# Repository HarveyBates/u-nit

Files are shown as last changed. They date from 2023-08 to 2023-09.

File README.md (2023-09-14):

<p align="center">
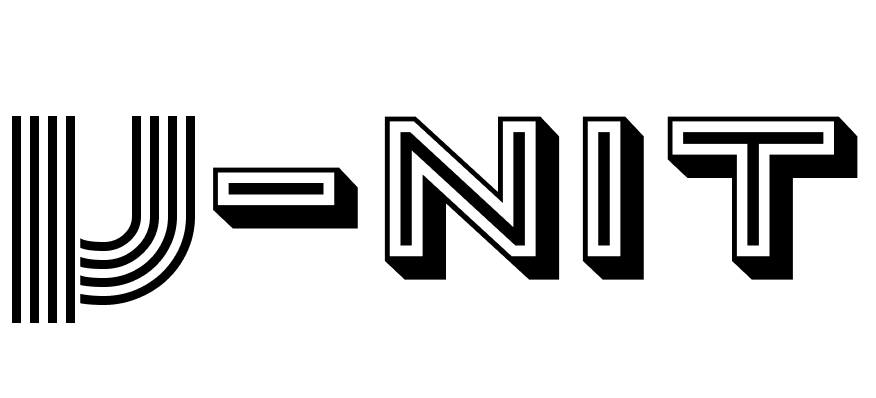
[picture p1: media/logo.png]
  
</p>

An STM32 based general purpose board designed for mixed signal applications. 

### Features:

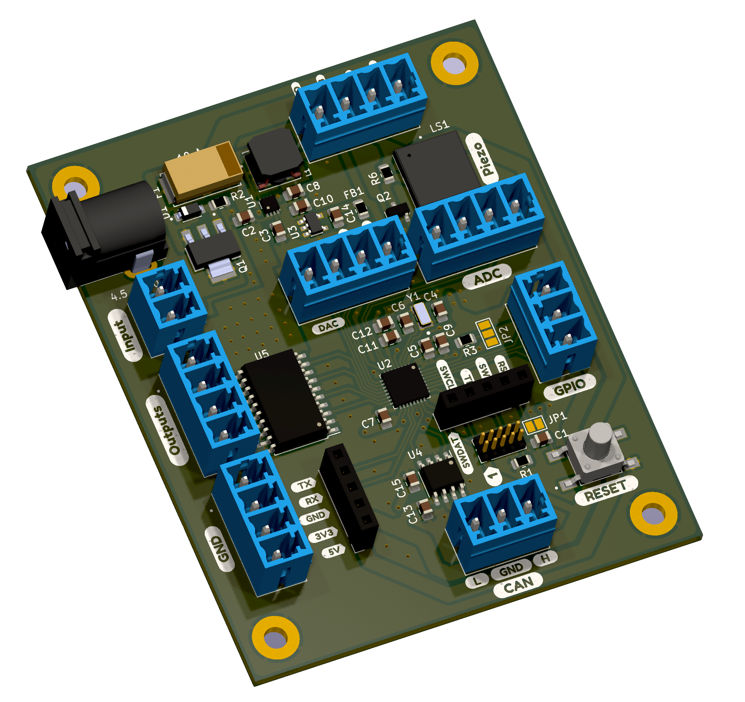
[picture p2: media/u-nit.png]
  

- Wide input voltage (4.5 - 40 VDC)
- Palm size (65 mm x 80 mm)
- Replaceable fuse (10 A) and reverse-polarity protection
- Line regulation and outputs (VIN, 5V, 3V3)
- CAN transceiver built in with 120 ohm termination
- Debug through ST-Link (2 connector varieties)
- 4 high-power, high-side switches (2 A per channel or 6 A if chained)
- General purpose interfaces (2 USART, 2 ADC, 2 DAC, 1 I2C, >1 GPI)
- Piezo buzzer for audible feedback

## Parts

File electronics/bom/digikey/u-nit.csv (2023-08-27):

Index | Manufacturer Part Number | Manufacturer Name | Description | Availability | Stock Status | Attrition % | Requested Quantity 1 | Pack Quantity 1 | Pack Type 1 | Digi-Key Part Number 1 | Unit Price 1 | Extended Price 1 | Minimum Order Quantity 1 | Customer Reference | Requested Part Number | Datasheet
1 | TBP02R2-381-02BE | CUI Devices | TERMINAL BLOCK, PLUGGABLE, 3.81, | 16,501 | In Stock |  | 1 | 1 | Bag | 102-6492-ND | 0.96000 | $0.96 | 1 |  | TBP02R2-381-02BE | https://www.cuidevices.com/product/resource/tbp02r2-381.pdf
2 | PJ-002A | CUI Devices | CONN PWR JACK 2X5.5MM SOLDER | 80,252 | In Stock |  | 1 | 1 | Bag | CP-002A-ND | 1.14000 | $1.14 | 1 |  | PJ-002A | https://www.cuidevices.com/product/resource/pj-002a.pdf
3 | TBP02R2-381-04BE | CUI Devices | TERMINAL BLOCK, PLUGGABLE, 3.81, | 1,261 | In Stock |  | 5 | 5 | Bag | 102-6494-ND | 1.33000 | $6.65 | 1 |  | TBP02R2-381-04BE | https://www.cuidevices.com/product/resource/tbp02r2-381.pdf
4 | TBP02R2-381-03BE | CUI Devices | TERMINAL BLOCK, PLUGGABLE, 3.81, | 7,207 | In Stock |  | 2 | 2 | Bag | 102-6493-ND | 1.10000 | $2.20 | 1 |  | TBP02R2-381-03BE | https://www.cuidevices.com/product/resource/tbp02r2-381.pdf
5 | DMP6023LE-13 | Diodes Incorporated | MOSFET P-CH 60V 7A/18.2A SOT223 | 12,408 | In Stock |  | 1 | 1 | Cut Tape (CT) | DMP6023LE-13DICT-ND | 1.30000 | $1.30 | 1 |  | DMP6023LE-13 | https://www.diodes.com/assets/Datasheets/DMP6023LE.pdf
6 | STM32L432KCU6 | STMicroelectronics | IC MCU 32BIT 256KB FLSH 32UFQFPN | 15,711 | In Stock |  | 1 | 1 | Tray | 497-16578-ND | 10.76000 | $10.76 | 1 |  | STM32L432KCU6 | https://www.st.com/content/ccc/resource/technical/document/datasheet/24/01/9f/59/f0/83/47/fc/DM00257205.pdf/files/DM00257205.pdf/jcr:content/translations/en.D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
7 | ADP122AUJZ-3.3-R7 | Analog Devices Inc. | IC REG LINEAR 3.3V 300MA TSOT5 | 51,764 | In Stock |  | 1 | 1 | Cut Tape (CT) | 505-ADP122AUJZ-3.3-R7CT-ND | 2.55000 | $2.55 | 1 |  | ADP122AUJZ-3.3-R7 | https://www.analog.com/media/en/technical-documentation/data-sheets/ADP122_123.pdf
8 | ITS716GFUMA1 | Infineon Technologies | IC PWR SWITCH N-CHAN 1:1 DSO-20 | 2,884 | In Stock |  | 1 | 1 | Cut Tape (CT) | ITS716GFUMA1CT-ND | 7.19000 | $7.19 | 1 |  | ITS716G | https://www.infineon.com/dgdl/Infineon-ITS716G-DS-v01_01-en.pdf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
9 | ECS-.327-12.5-34R-C-TR | ECS Inc. | CRYSTAL 32.7680KHZ 12.5PF SMD | 18,439 | In Stock |  | 1 | 1 | Cut Tape (CT) | XC2127CT-ND | 1.28000 | $1.28 | 1 |  | ECS-.327-12.5-34R-C-TR | https://ecsxtal.com/store/pdf/ECX_34R.pdf
10 | CL10B104KC8NNNC | Samsung Electro-Mechanics | CAP CER 0.1UF 100V X7R 0603 | 1,657,410 | In Stock |  | 5 | 5 | Cut Tape (CT) | 1276-6807-1-ND | 0.16000 | $0.80 | 1 |  | 1276-6807-1-ND | http://mm.digikey.com/Volume0/opasdata/d220001/medias/docus/1296/CL10B104KC8NNNC_Spec.pdf
11 | KAM21KR72A105KU | KYOCERA AVX | CAP CER 1UF 100V X7R 0805 | 53,949 | In Stock |  | 5 | 5 | Cut Tape (CT) | 478-KAM21KR72A105KUCT-ND | 0.52000 | $2.60 | 1 |  | 478-KAM21KR72A105KUCT-ND | https://datasheets.kyocera-avx.com/AutoMLCC.pdf
12 | C0805C100J3HAC7800 | KEMET | CAP CER 10PF 25V X8R 0805 | 22,533 | In Stock |  | 2 | 2 | Cut Tape (CT) | 399-C0805C100J3HAC7800CT-ND | 0.16000 | $0.32 | 1 |  | 399-C0805C100J3HAC7800CT-ND | https://connect.kemet.com:7667/gateway/IntelliData-ComponentDocumentation/1.0/download/datasheet/C0805C100J3HAC7800
13 | CL21A475KAQNNNE | Samsung Electro-Mechanics | CAP CER 4.7UF 25V X5R 0805 | 3,934,922 | In Stock |  | 1 | 1 | Cut Tape (CT) | 1276-1244-1-ND | 0.16000 | $0.16 | 1 |  | 1276-1244-1-ND | http://mm.digikey.com/Volume0/opasdata/d220001/medias/docus/41/CL21A475KAQNNNE_Spec.pdf
14 | C0805C103K5RECAUTO | KEMET | CAP CER 0805 10NF 50V X7R 10% | 27,445 | In Stock |  | 1 | 1 | Cut Tape (CT) | 399-17885-1-ND | 0.39000 | $0.39 | 1 |  | 399-17885-1-ND | https://connect.kemet.com:7667/gateway/IntelliData-ComponentDocumentation/1.0/download/datasheet/C0805C103K5RECAUTO
15 | MMSZ4700T1G | onsemi | DIODE ZENER 13V 500MW SOD123 | 69,197 | In Stock |  | 1 | 1 | Cut Tape (CT) | MMSZ4700T1GOSCT-ND | 0.42000 | $0.42 | 1 |  | MMSZ4700T1GOSCT-ND | https://www.onsemi.com/pdf/datasheet/mmsz4678t1-d.pdf
16 | 0154010.DRL | Littelfuse Inc. | FUSE BRD MNT 10A 125VAC/VDC 2SMD | 4,180 | In Stock |  | 1 | 1 | Cut Tape (CT) | F11011CT-ND | 5.37000 | $5.37 | 1 |  | F11011CT-ND | https://www.littelfuse.com/~/media/electronics/datasheets/fuses/littelfuse_fuse_154_154t_154l_154tl_datasheet.pdf.pdf
17 | 2508051027Y1 | Fair-Rite Products Corp. | FERRITE BEAD 1K OHM 0805 1LN | 134,499 | In Stock |  | 1 | 1 | Cut Tape (CT) | 1934-1009-1-ND | 0.16000 | $0.16 | 1 |  | 1934-1009-1-ND | https://www.fair-rite.com/wp-content/themes/fair-rite/print_product.php?pid=19184
18 | GRPB052VWVN-RC | Sullins Connector Solutions | CONN HEADER VERT 10POS 1.27MM | 31,971 | In Stock |  | 1 |  |  |  |  |  |  |  | S9015E-05-ND | https://s3.amazonaws.com/catalogspreads-pdf/PAGE94-95%20.050%20MALE%20HDR%20ST%20RA%20SMT.pdf
19 | VLS6045EX-470M | TDK Corporation | FIXED IND 47UH 1.3A 299 MOHM SMD | 124,341 | In Stock |  | 1 | 1 | Cut Tape (CT) | 445-173054-1-ND | 0.67000 | $0.67 | 1 |  | 445-173054-1-ND | https://product.tdk.com/en/system/files
20 | PKMCS0909E4000-R1 | Murata Electronics | BUZZER PIEZO 1.5V 9X9MM SMD | 46,358 | In Stock |  | 1 | 1 | Cut Tape (CT) | 490-9647-1-ND | 1.43000 | $1.43 | 1 |  | 490-9647-1-ND | https://www.murata.com/~/media/webrenewal/products/sound/sounder/vppt-buzj083-d.ashx
21 | BC847BLT3G | onsemi | TRANS NPN 45V 0.1A SOT23-3 | 178,666 | In Stock |  | 1 | 1 | Cut Tape (CT) | BC847BLT3GOSCT-ND | 0.18000 | $0.18 | 1 |  | BC847BLT3GOSCT-ND | https://www.onsemi.com/pdf/datasheet/bc846alt1-d.pdf
22 | RNCP0805FTD10K0 | Stackpole Electronics Inc | RES 10K OHM 1% 1/4W 0805 | 205,753 | In Stock |  | 4 | 4 | Cut Tape (CT) | RNCP0805FTD10K0CT-ND | 0.16000 | $0.64 | 1 |  | RNCP0805FTD10K0CT-ND | https://www.seielect.com/catalog/sei-rncp.pdf
23 | RC0805FR-07120RL | YAGEO | RES 120 OHM 1% 1/8W 0805 | 208,422 | In Stock |  | 1 | 1 | Cut Tape (CT) | 311-120CRCT-ND | 0.16000 | $0.16 | 1 |  | 311-120CRCT-ND | https://www.yageo.com/upload/media/product/productsearch/datasheet/rchip/PYu-RC_Group_51_RoHS_L_12.pdf
24 | RNCP0805FTD1K00 | Stackpole Electronics Inc | RES 1K OHM 1% 1/4W 0805 | 400,904 | In Stock |  | 1 |  |  |  |  |  |  |  | RNCP0805FTD1K00CT-ND | https://www.seielect.com/catalog/sei-rncp.pdf
25 | TL3301AF160QG | E-Switch | SWITCH TACTILE SPST-NO 0.05A 12V | 11,208 | In Stock |  | 1 | 1 | Cut Tape (CT) | EG2526CT-ND | 0.68000 | $0.68 | 1 |  | EG2526CT-ND | https://eswitch.wpengine.com/wp-content/uploads/2022/06/TL3301-1.pdf
26 | MAX15062BATA+T | Analog Devices Inc./Maxim Integrated | IC REG BUCK 5V 300MA 8TDFN | 21,937 | In Stock |  | 1 | 1 | Cut Tape (CT) | MAX15062BATA+TCT-ND | 5.21000 | $5.21 | 1 |  | MAX15062BATA+TCT-ND | https://datasheets.maximintegrated.com/en/ds/MAX15062.pdf
27 | MCP2562FDT-E/SN | Microchip Technology | IC TRANSCEIVER 1/1 8SOIC | 6,739 | In Stock |  | 1 | 1 | Cut Tape (CT) | MCP2562FDT-E/SNCT-ND | 2.09000 | $2.09 | 1 |  | MCP2562FDT-E/SNCT-ND | https://ww1.microchip.com/downloads/en/DeviceDoc/20005284A.pdf
28 | PPPC051LFBN-RC | Sullins Connector Solutions | CONN HDR 5POS 0.1 GOLD PCB | 18,967 | In Stock |  | 2 | 2 | Tray | S7038-ND | 0.79000 | $1.58 | 1 |  | S7038-ND | http://mm.digikey.com/Volume0/opasdata/d220001/medias/docus/937/Female_Headers.100_DS.pdf

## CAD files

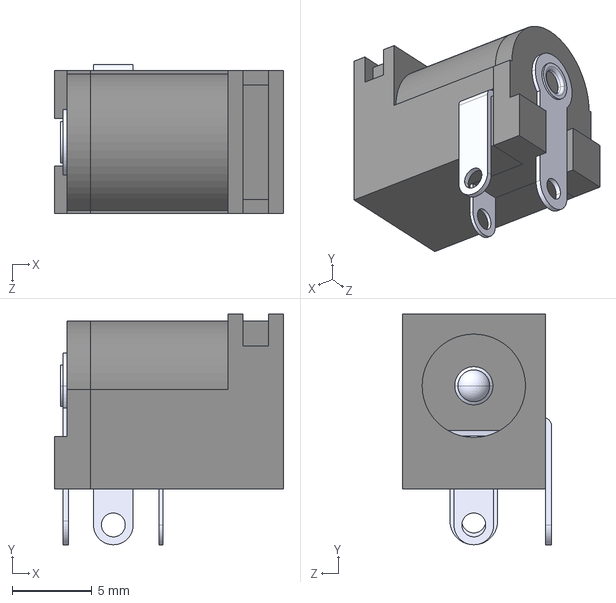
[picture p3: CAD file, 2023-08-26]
electronics/u-nit/components/extern/3dmodels/connectors/PJ-002A.step
14.4 x 14.5 x 9.40 mm

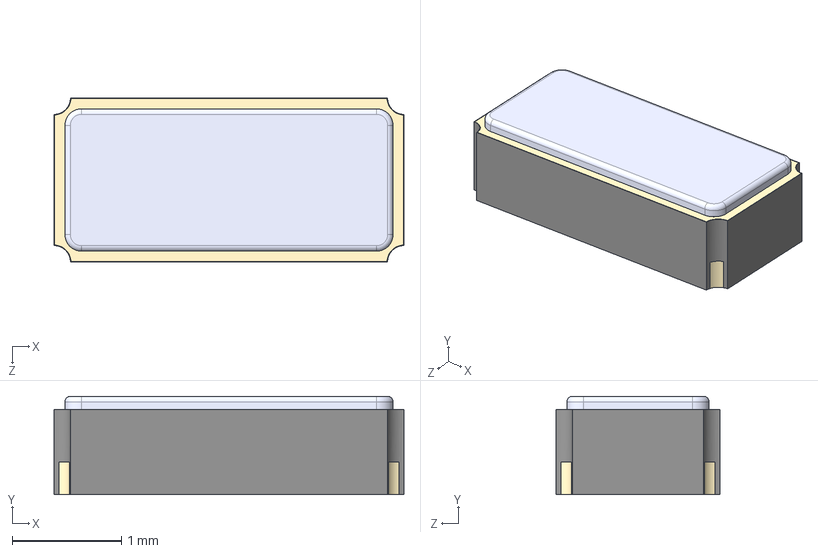
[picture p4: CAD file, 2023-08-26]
electronics/u-nit/components/extern/3dmodels/crystals/ECS-.327-12.5-34R-C-TR.step
3.20 x 0.9 x 1.50 mm

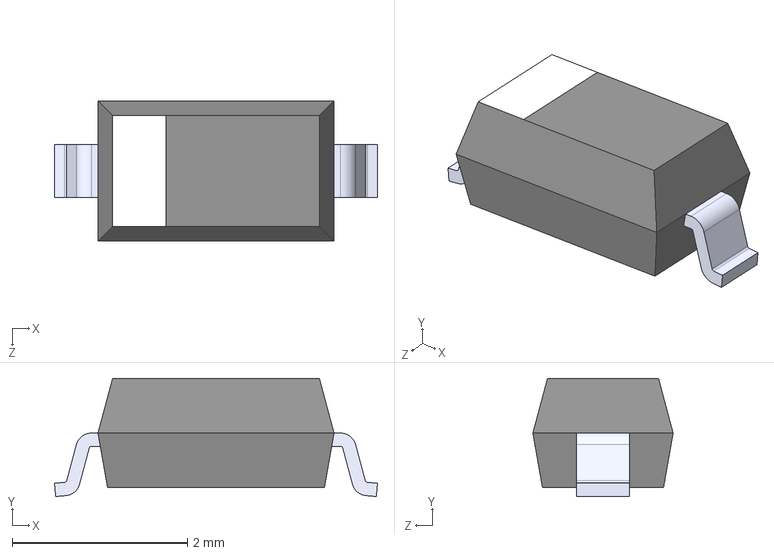
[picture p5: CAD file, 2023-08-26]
electronics/u-nit/components/extern/3dmodels/diodes/MMSZ4700T1G.step
3.68 x 1.35 x 1.60 mm

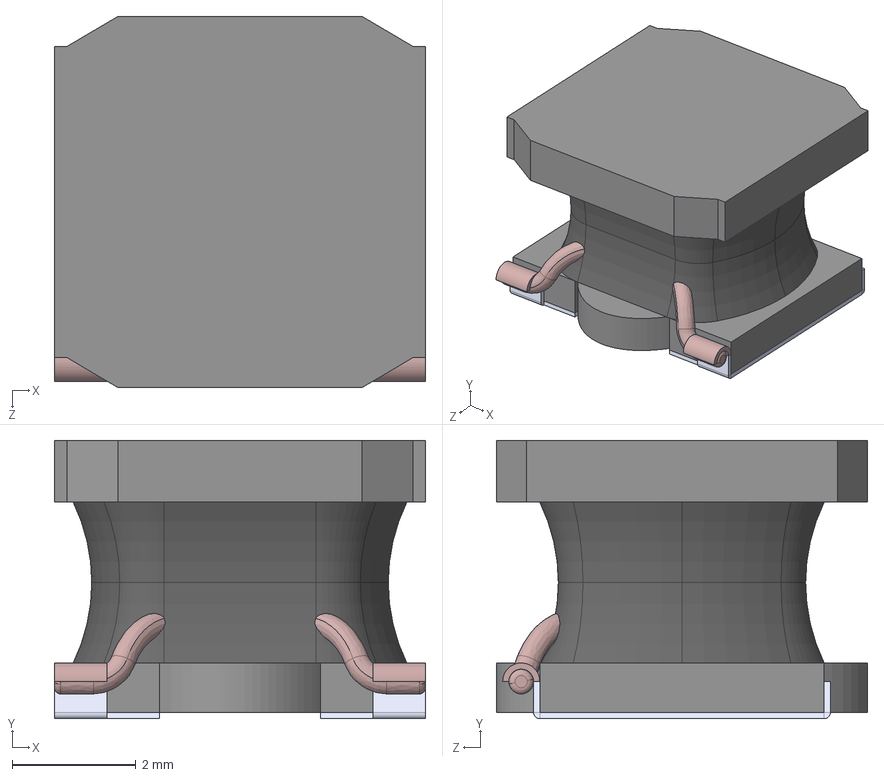
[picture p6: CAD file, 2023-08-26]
electronics/u-nit/components/extern/3dmodels/inductors/VLS6045EX-470M.step
6.00 x 4.50 x 6.00 mm

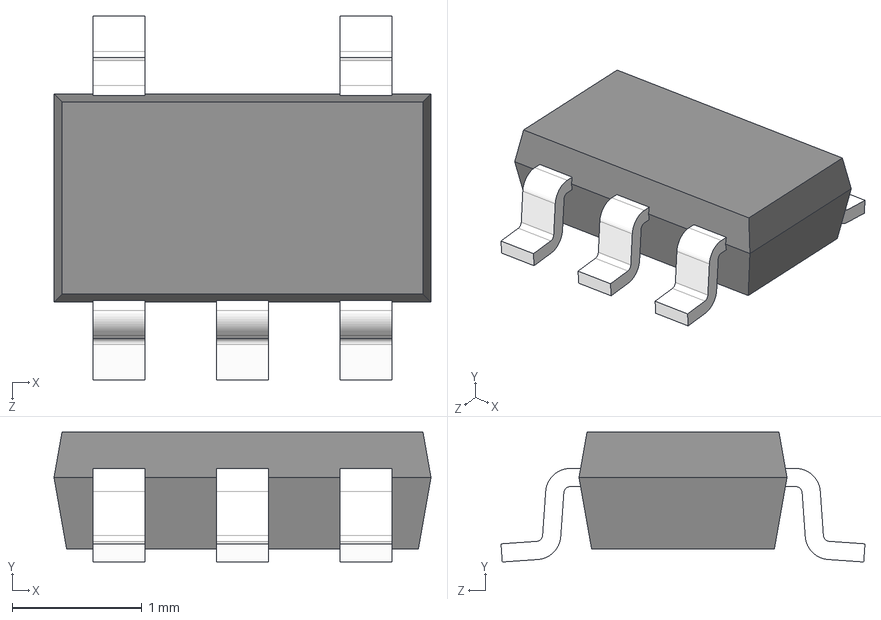
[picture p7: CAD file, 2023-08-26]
electronics/u-nit/components/extern/3dmodels/ldo/ADP122AUJZ-3.3-R7.step
2.90 x 1.00 x 2.80 mm

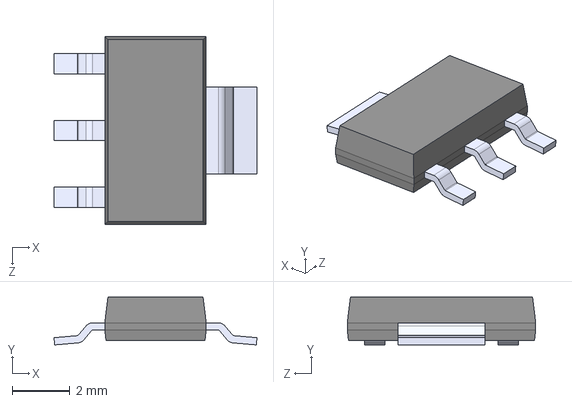
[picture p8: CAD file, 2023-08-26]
electronics/u-nit/components/extern/3dmodels/mosfets/DMP6023LE-13.step
7.00 x 1.65 x 6.50 mm

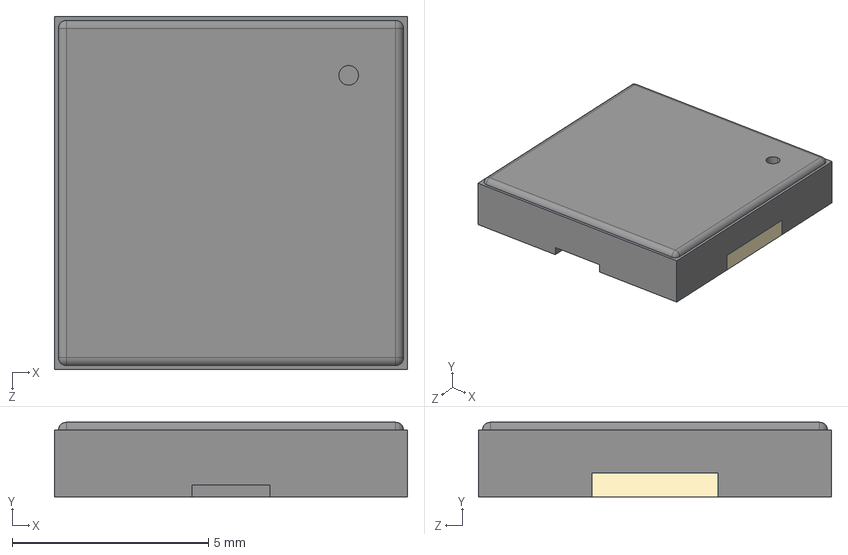
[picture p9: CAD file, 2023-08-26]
electronics/u-nit/components/extern/3dmodels/piezo/PKMCS0909E4000-R1.step
9.00 x 1.90 x 9.00 mm

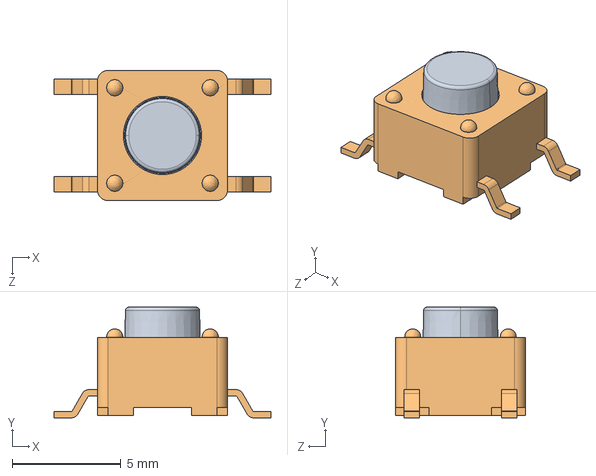
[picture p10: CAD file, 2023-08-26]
electronics/u-nit/components/extern/3dmodels/switch_tactile/TL3301AF160QG.step
10.0 x 5.10 x 6.00 mm

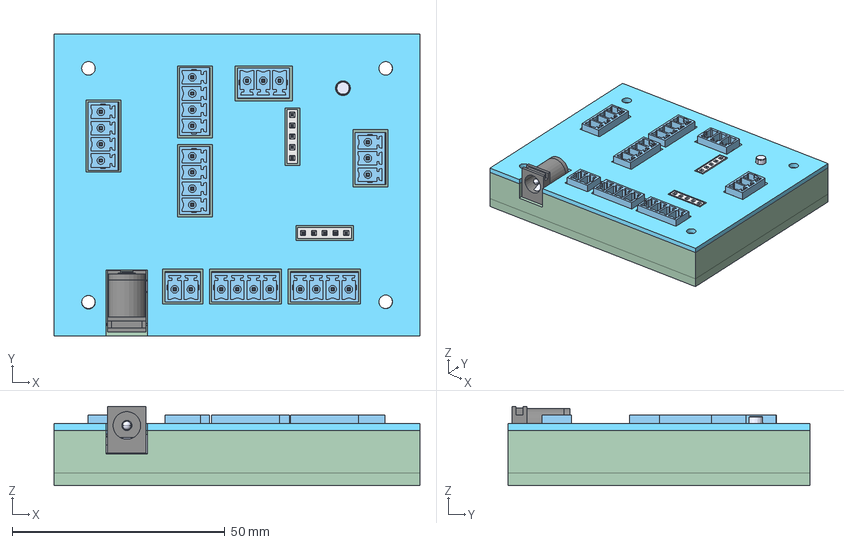
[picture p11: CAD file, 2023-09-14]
models/enclosure/base.FCStd
86.0 x 71.0 x 18.6 mm
Base_Body
u-nit PCB
Lid_Body

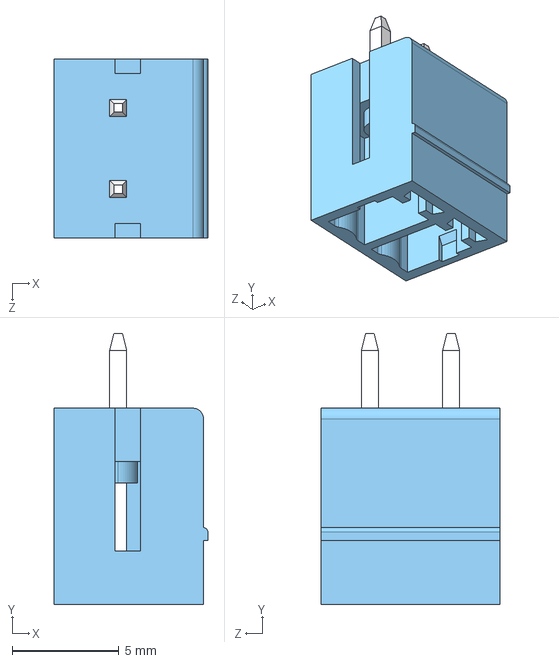
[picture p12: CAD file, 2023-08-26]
electronics/u-nit/components/extern/3dmodels/connectors/TBP02R2-381-02BE.step
7.20 x 12.7 x 8.41 mm

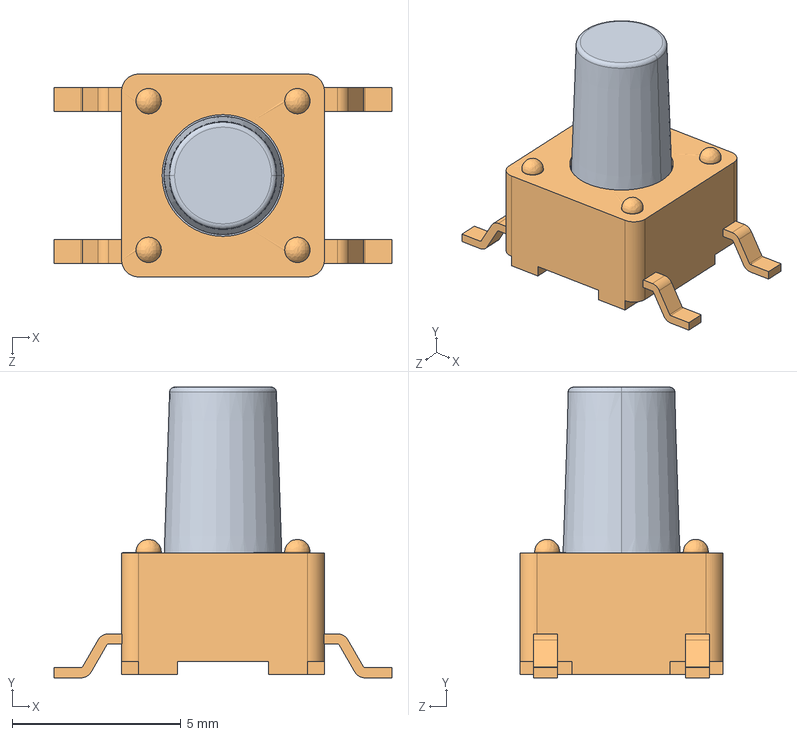
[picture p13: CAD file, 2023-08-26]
electronics/u-nit/components/extern/3dmodels/switch_tactile/TL3301PF160QG.STEP
10.0 x 8.60 x 6.00 mm

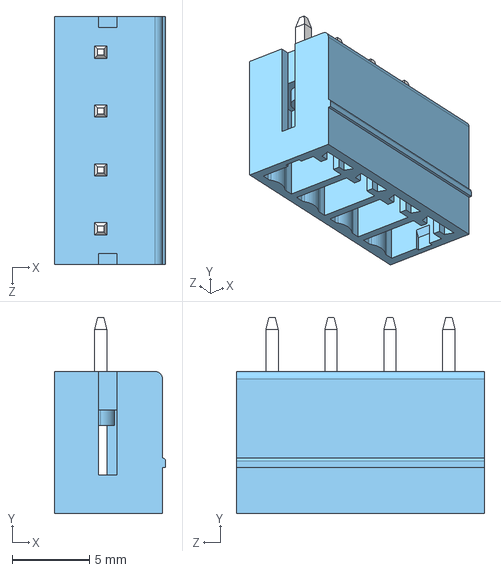
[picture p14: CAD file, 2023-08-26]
electronics/u-nit/components/extern/3dmodels/connectors/TBP02R2-381-04BE.step
7.20 x 12.7 x 16.0 mm

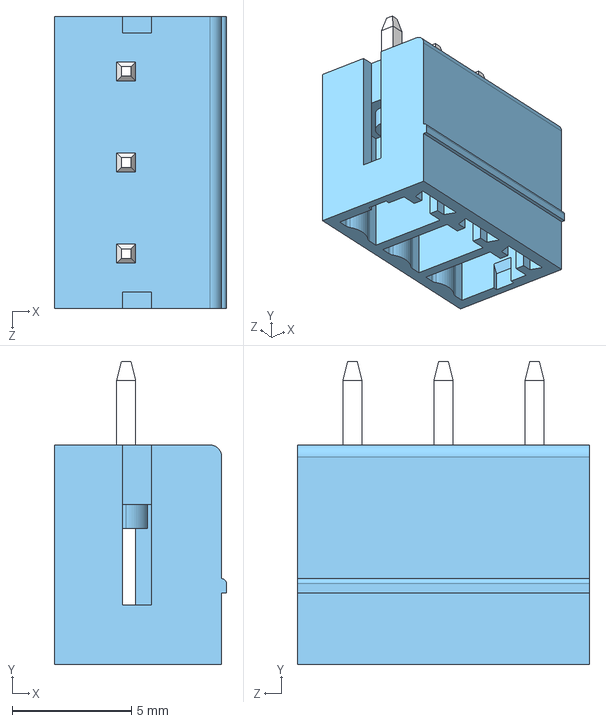
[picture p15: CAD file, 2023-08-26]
electronics/u-nit/components/extern/3dmodels/connectors/TBP02R2-381-03BE.step
7.20 x 12.7 x 12.2 mm

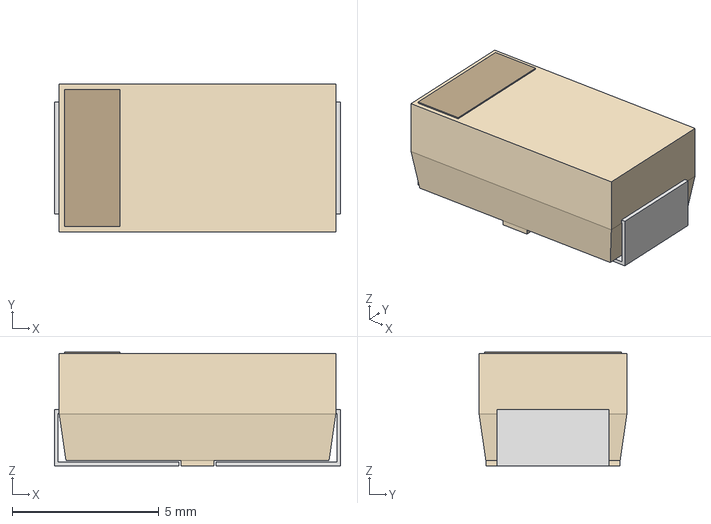
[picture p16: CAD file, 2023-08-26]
electronics/u-nit/components/extern/3dmodels/fuses/0154010.DRL.step
9.73 x 5.03 x 3.86 mm

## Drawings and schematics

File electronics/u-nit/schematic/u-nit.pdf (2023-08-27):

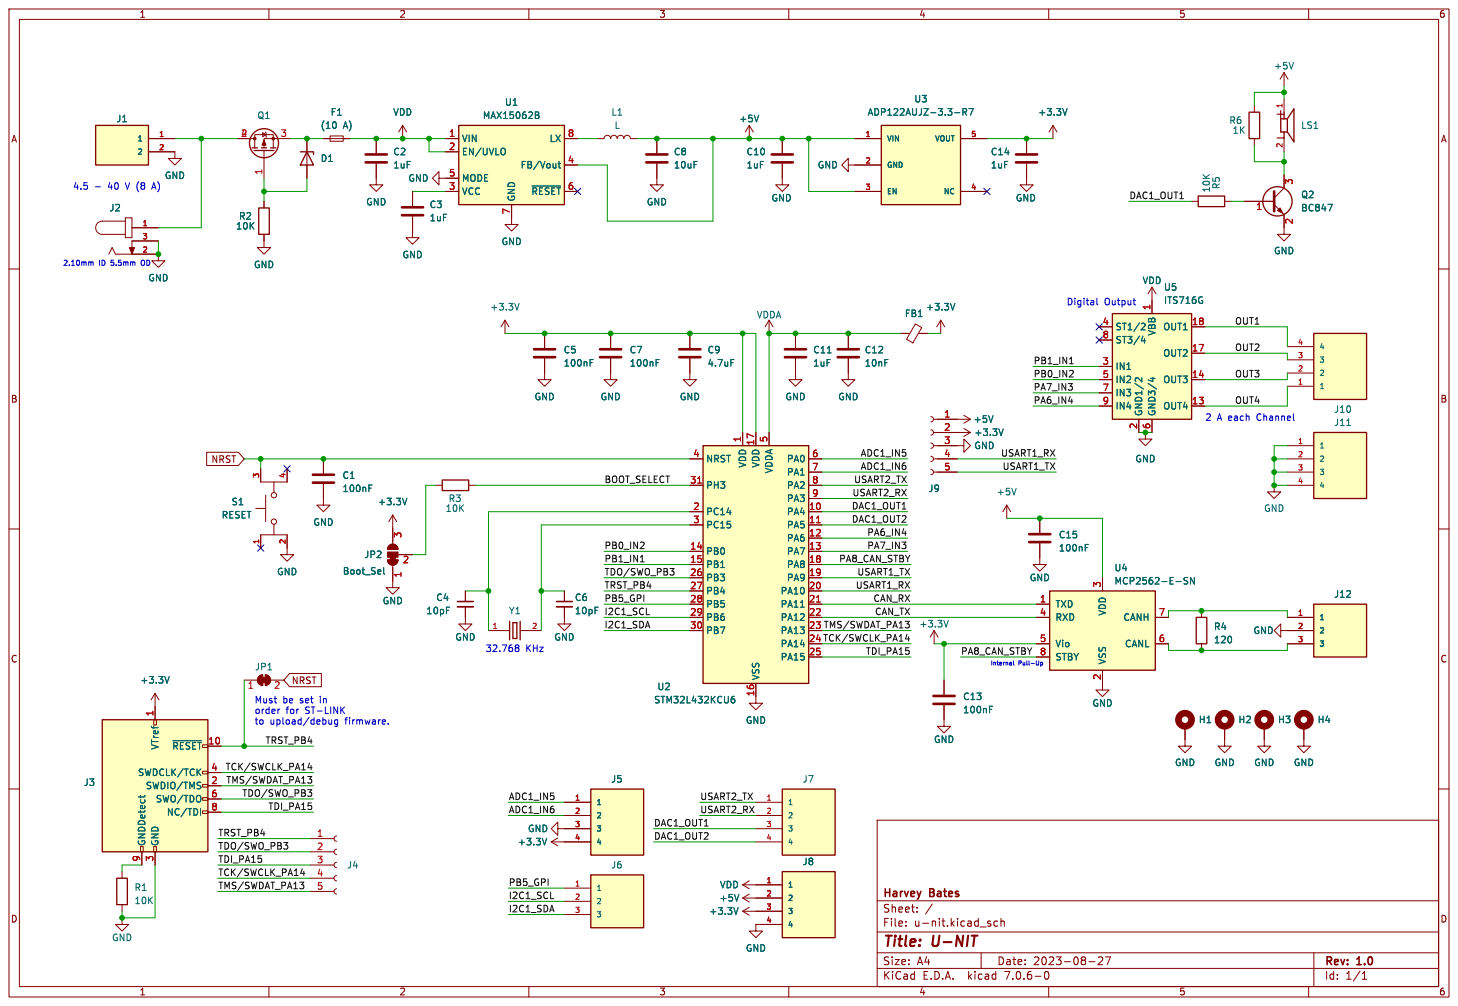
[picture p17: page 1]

3 SWDCLK/TCK 4 SWO/TDO 6 NC/TDI 8 GNDDetect 9 F1 VDD

1 PA4 10 PA5 11 PA6 12 PA7 13 PB0 14 PB1 15 VSS 16 VDD 17 PA8 18 PA9 19 PC14 2 PA10 20 PA11 21 PA12 22 PA13 23 PA14 24 PA15 25 PB3 26 PB4 27 PB5 28 PB6 29 PC15 3 PB7 30 PH3 31 NRST 4 VDDA

3 RXD 4 Vio 5 CANL 6 CANH 7 STBY 8 U4 MCP2562-E-SN GND GND

3 RXD 4 Vio 5 CANL 6 CANH 7 STBY 8 GND R4

32.768 KHz Must be set in

order for ST-LINK

3 SWDCLK/TCK 4 SWO/TDO 6 NC/TDI 8 GNDDetect 9

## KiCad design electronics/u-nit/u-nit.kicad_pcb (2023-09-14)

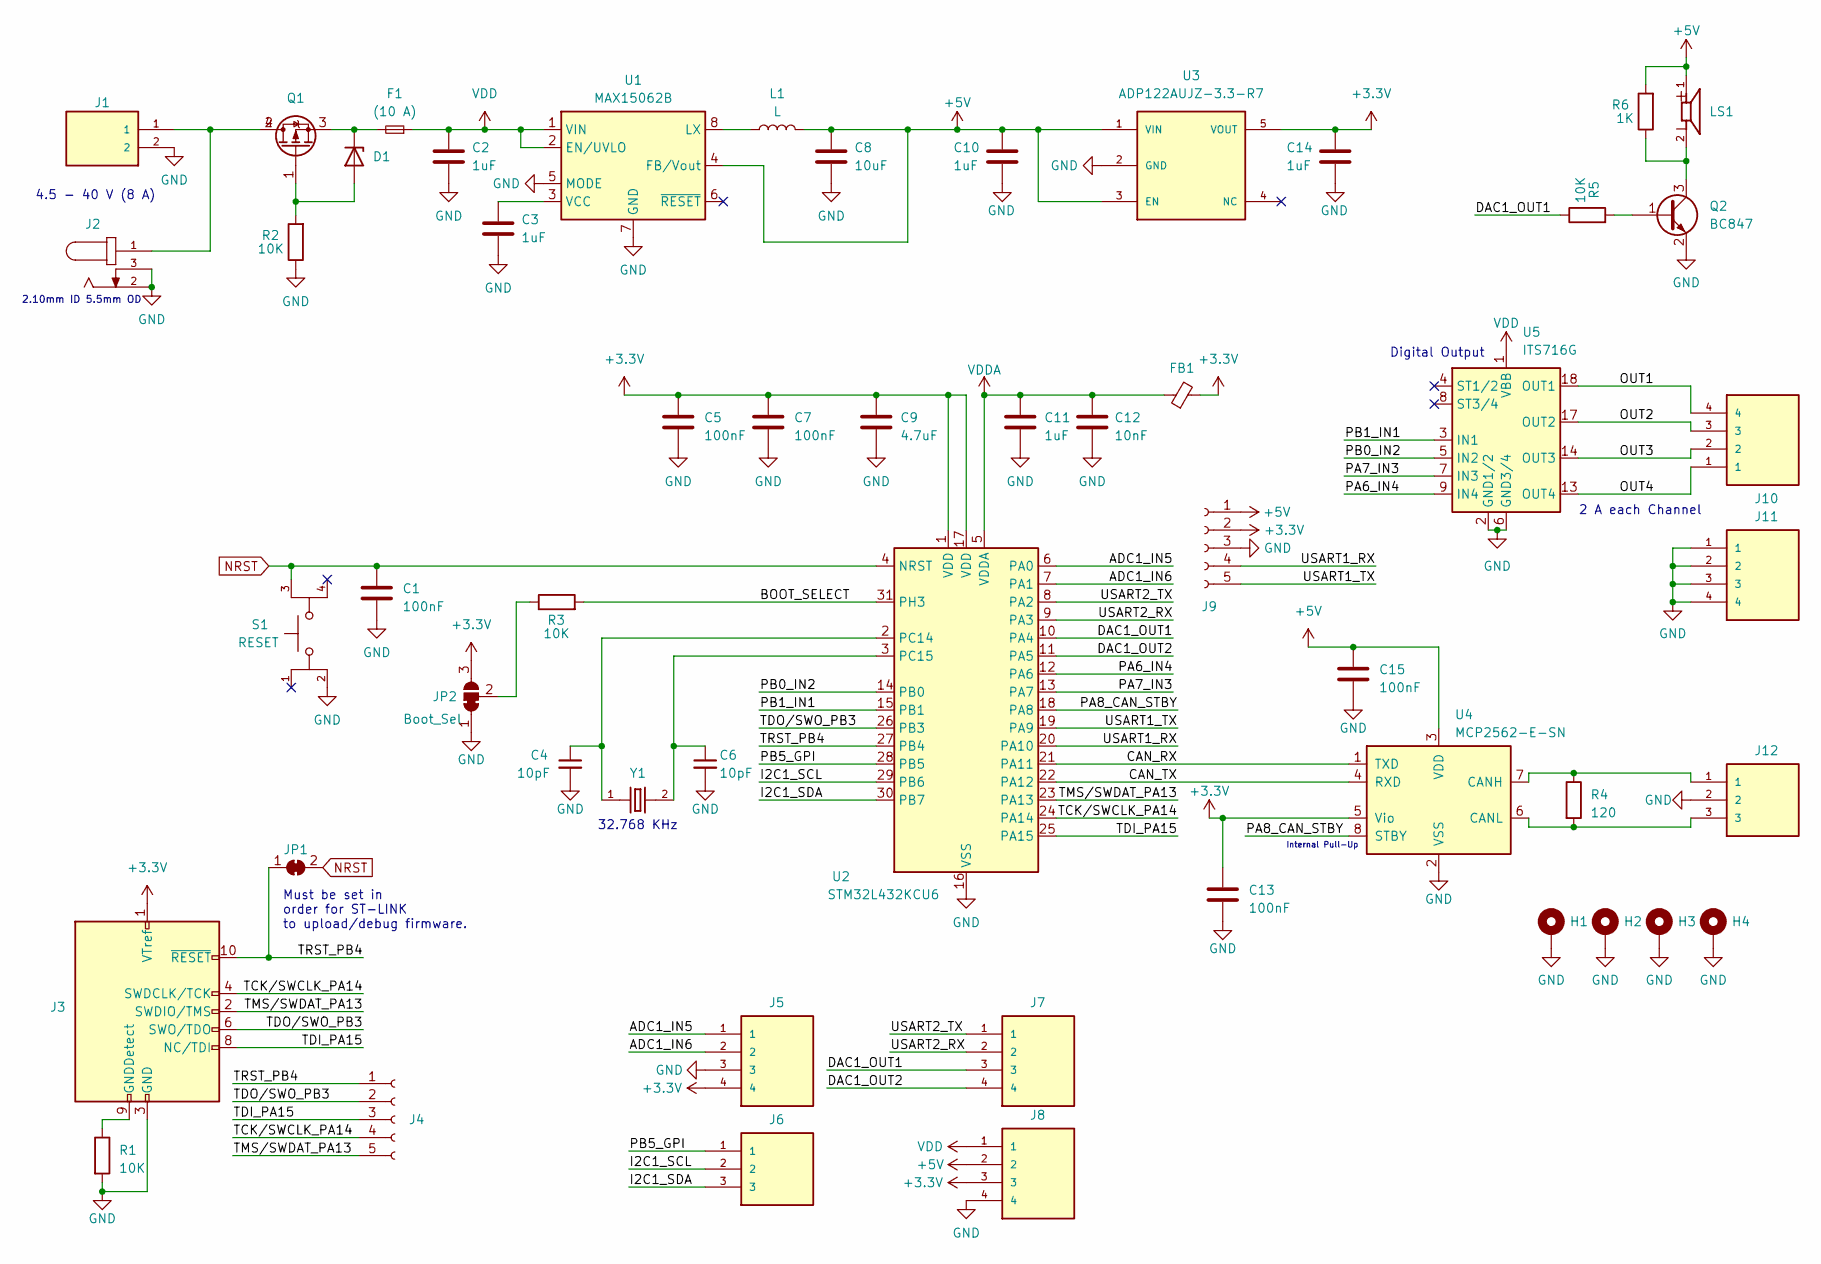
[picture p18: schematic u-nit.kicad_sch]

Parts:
C1, C5, C7, C13, C15: 100nF; C_0805_2012Metric
C2, C3, C10, C11, C14: 1uF; C_0805_2012Metric
C4, C6: 10pF; C_0805_2012Metric
C8: 10uF; C_0805_2012Metric
C9: 4.7uF; C_0805_2012Metric
C12: 10nF; C_0805_2012Metric
D1: D_Zener; MMSZ4700T1G
F1: (10 A); 0154010.DRL; Part 0154010.DRL
FB1: R_0805_2012Metric; Part 2508051027Y1
H1, H2, H3, H4: MountingHole_Pad; MountingHole_3.2mm_M3_Pad_TopBottom
J1: TBP02R2-381-02BE
J2: PJ-002A
J3: Conn_ARM_JTAG_SWD_10; PinHeader_2x05_P1.27mm_Vertical; Part GRPB052VWVN-RC
J4, J9: Conn_01x05_Socket; PinSocket_1x05_P2.54mm_Vertical
J5, J7, J8, J10, J11: TBP02R2-381-04BE
J6, J12: TBP02R2-381-03BE
JP1: SolderJumper-2_P1.3mm_Bridged_Pad1.0x1.5mm
JP2: Boot_Sel; SolderJumper-3_P1.3mm_Bridged12_Pad1.0x1.5mm_NumberLabels
L1: L; VLS6045EX-470M; Part VLS6045EX-470M
LS1: PKMCS0909E4000-R1; PARTREV May 22, 2020
Q1: DMP6023LE-13
Q2: BC847; SOT-23
R1, R2, R3, R5: 10K; R_0805_2012Metric
R4: 120; R_0805_2012Metric
R6: 1K; R_0805_2012Metric
S1: RESET; TL3301AF160QG; PARTREV E; DigiKey_Part_Number EG2526TR-ND
U1: MAX15062B; DFN-8_2x2mm_P0.5mm
U2: STM32L432KCU6; QFN-32-1EP_5x5mm_P0.5mm_EP3.45x3.45mm
U3: ADP122AUJZ-3.3-R7
U4: MCP2562-E-SN; SOIC-8_3.9x4.9mm_P1.27mm
U5: ITS716G; SOIC-20W_7.5x12.8mm_P1.27mm
Y1: ECS-.327-12.5-34R-C-TR; PARTREV 2016

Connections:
+3.3V: C5.1, C7.1, C9.1, C13.1, C14.1, FB1.2, J3.1 (VTref), J5.4, J8.3, J9.2, JP2.3 (B), U2.1 (VDD), U2.17 (VDD), U3.5 (VOUT), U4.5 (Vio)
+5V: C8.1, C10.1, C15.1, J8.2, J9.1, L1.2, LS1.1, R6.2, U1.4 (FB/Vout), U3.1 (VIN), U3.3 (EN), U4.3 (VDD)
/ADC1_IN5: J5.1, U2.6 (PA0)
/ADC1_IN6: J5.2, U2.7 (PA1)
/BOOT_SELECT: R3.2, U2.31 (PH3)
/CAN_RX: U2.21 (PA11), U4.1 (TXD)
/CAN_TX: U2.22 (PA12), U4.4 (RXD)
/DAC1_OUT1: J7.3, R5.1, U2.10 (PA4)
/DAC1_OUT2: J7.4, U2.11 (PA5)
/I2C1_SCL: J6.2, U2.29 (PB6)
/I2C1_SDA: J6.3, U2.30 (PB7)
/OUT1: J10.4, U5.18 (OUT1)
/OUT2: J10.3, U5.17 (OUT2)
/OUT3: J10.2, U5.14 (OUT3)
/OUT4: J10.1, U5.13 (OUT4)
/PA6_IN4: U2.12 (PA6), U5.9 (IN4)
/PA7_IN3: U2.13 (PA7), U5.7 (IN3)
/PA8_CAN_STBY: U2.18 (PA8), U4.8 (STBY)
/PB0_IN2: U2.14 (PB0), U5.5 (IN2)
/PB1_IN1: U2.15 (PB1), U5.3 (IN1)
/PB5_GPI: J6.1, U2.28 (PB5)
/TCK/SWCLK_PA14: J3.4 (SWDCLK/TCK), J4.4, U2.24 (PA14)
/TDI_PA15: J3.8 (NC/TDI), J4.3, U2.25 (PA15)
/TDO/SWO_PB3: J3.6 (SWO/TDO), J4.2, U2.26 (PB3)
/TMS/SWDAT_PA13: J3.2 (SWDIO/TMS), J4.5, U2.23 (PA13)
/TRST_PB4: J3.10 (~RESET), J4.1, JP1.1 (A), U2.27 (PB4)
/USART1_RX: J9.4, U2.20 (PA10)
/USART1_TX: J9.5, U2.19 (PA9)
/USART2_RX: J7.2, U2.9 (PA3)
/USART2_TX: J7.1, U2.8 (PA2)
GND: C1.2, C2.2, C3.2, C4.2, C5.2, C6.2, C7.2, C8.2, C9.2, C10.2, C11.2, C12.2, C13.2, C14.2, C15.2, H1.1, H2.1, H3.1, H4.1, J1.2, J2.2, J2.3, J3.3 (GND), J3.5 (GND), J5.3, J8.4, J9.3, J11.1, J11.2, J11.3, J11.4, J12.2, JP2.1 (A), Q2.2 (E), R1.2, R2.1, S1.2, U1.5 (MODE), U1.7 (GND), U2.16 (VSS), U2.32 (VSS), U2.33 (VSS), U3.2 (GND), U4.2 (VSS), U5.2 (GND1/2), U5.6 (GND3/4)
NRST: C1.1, JP1.2 (B), S1.3, U2.4 (NRST)
unnamed: D1.2 (A), Q1.1, R2.2
unnamed: D1.1 (K), F1.2, Q1.3
unnamed: J1.1, J2.1, Q1.2, Q1.4
unnamed: J3.9 (GNDDetect), R1.1
unnamed: JP2.2 (C), R3.1
unnamed: Q2.1 (B), R5.2
unnamed: LS1.2, Q2.3 (C), R6.1
unnamed: L1.1, U1.8 (LX)
unnamed: C3.1, U1.3 (VCC)
unnamed: C4.1, U2.2 (PC14), Y1.1
unnamed: C6.1, U2.3 (PC15), Y1.2
unnamed: J12.1, R4.1, U4.7 (CANH)
unnamed: J12.3, R4.2, U4.6 (CANL)
VDD: C2.1, F1.1, J8.1, U1.1 (VIN), U1.2 (EN/UVLO), U5.1 (VBB), U5.10 (VBB), U5.11 (VBB), U5.12 (VBB), U5.15 (VBB), U5.16 (VBB), U5.19 (VBB), U5.20 (VBB)
VDDA: C11.1, C12.1, FB1.1, U2.5 (VDDA)

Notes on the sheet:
Internal Pull-Up
Digital Output
2 A each Channel
32.768 KHz
2.10mm ID 5.5mm OD
Must be set in order for ST-LINK to upload/debug firmware.
4.5 - 40 V (8 A)

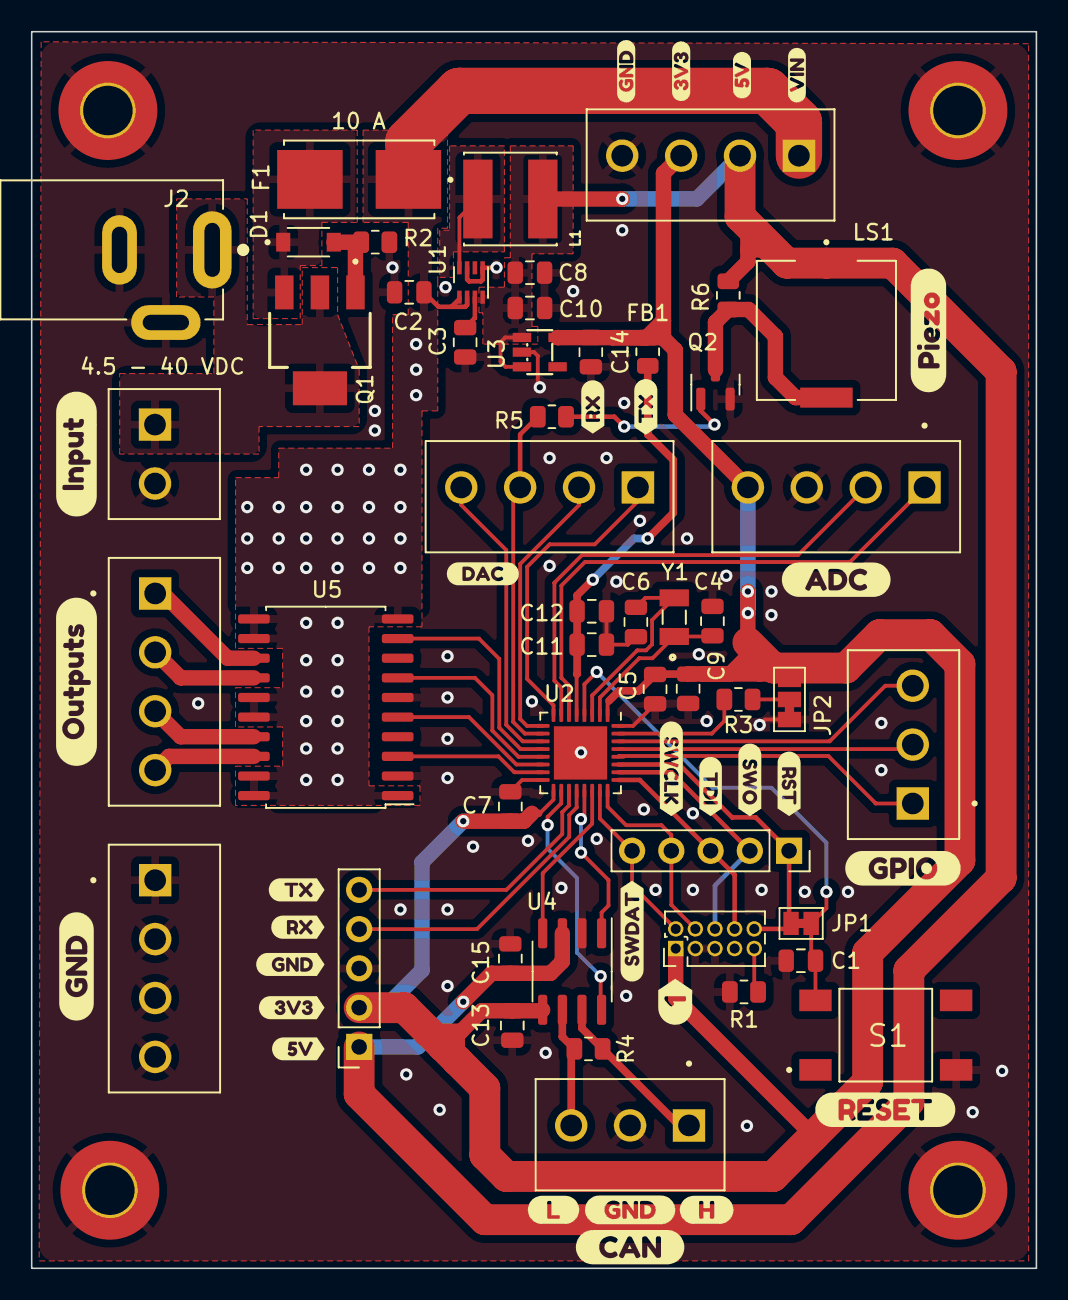
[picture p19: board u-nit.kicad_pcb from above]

Board: 2 copper layers, 65.0 x 80.0 mm, 82 parts (0 on the bottom side), 47 nets.

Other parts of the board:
kibuzzard-64E9E9CD: G***; kibuzzard-64E9E9CD
kibuzzard-64E9E96D: G***; kibuzzard-64E9E96D
kibuzzard-64E9E97D: G***; kibuzzard-64E9E97D
kibuzzard-64E9E988: G***; kibuzzard-64E9E988
kibuzzard-64E9E995: G***; kibuzzard-64E9E995
kibuzzard-64E9EA0B: G***; kibuzzard-64E9EA0B
kibuzzard-64E9EA19: G***; kibuzzard-64E9EA19
kibuzzard-64E9EAB8: G***; kibuzzard-64E9EAB8
kibuzzard-64E9EAC2: G***; kibuzzard-64E9EAC2
kibuzzard-64E9EAE9: G***; kibuzzard-64E9EAE9
kibuzzard-64E9EAF9: G***; kibuzzard-64E9EAF9
kibuzzard-64E9EB1A: G***; kibuzzard-64E9EB1A
kibuzzard-64E9EB3C: G***; kibuzzard-64E9EB3C
kibuzzard-64E9EB5A: G***; kibuzzard-64E9EB5A
kibuzzard-64E9EB76: G***; kibuzzard-64E9EB76
kibuzzard-64E9EBA4: G***; kibuzzard-64E9EBA4
kibuzzard-64E9EBD0: G***; kibuzzard-64E9EBD0
kibuzzard-64E9EBDF: G***; kibuzzard-64E9EBDF
kibuzzard-64E9EBEF: G***; kibuzzard-64E9EBEF
kibuzzard-64E9EC0B: G***; kibuzzard-64E9EC0B
kibuzzard-64E9EC1A: G***; kibuzzard-64E9EC1A
kibuzzard-64E9EC2C: G***; kibuzzard-64E9EC2C
kibuzzard-64E9EC3B: G***; kibuzzard-64E9EC3B
kibuzzard-64E9EC5C: G***; kibuzzard-64E9EC5C
kibuzzard-64E9EC20: G***; kibuzzard-64E9EC20
kibuzzard-64E9EC55: G***; kibuzzard-64E9EC55
kibuzzard-64E9EC76: G***; kibuzzard-64E9EC76
kibuzzard-64E9EC92: G***; kibuzzard-64E9EC92
kibuzzard-64E9ECC2: G***; kibuzzard-64E9ECC2

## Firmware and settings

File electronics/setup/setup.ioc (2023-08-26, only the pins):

Mcu.UserName=STM32L432KCUx
PA0.Signal=ADCx_IN5
PA1.Signal=ADCx_IN6
PA10.Signal=USART1_RX
PA11.Signal=CAN1_RX
PA12.Signal=CAN1_TX
PA2.Signal=USART2_TX
PA3.Signal=USART2_RX
PA4.Signal=COMP_DAC11_group
PA5.Signal=COMP_DAC12_group
PA6.Signal=GPIO_Output
PA7.Signal=GPIO_Output
PA8.Signal=GPIO_Output
PA9.Signal=USART1_TX
PB0.Signal=GPIO_Output
PB1.Signal=GPIO_Output
PB5.Signal=GPIO_Input
PB6.Signal=I2C1_SCL
PB7.Signal=I2C1_SDA

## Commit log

2023-08-27 exported PCB step and created base container
    [base.FCStd, u-nit.kicad_pcb]
2023-08-27 added digikey BOM, schematic (pdf) and gerber files
    [u-nit-B_Cu.gbr, u-nit-B_Mask.gbr, u-nit-B_Paste.gbr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]
2023-08-27 added bom and img
    [u-nit.csv]
2023-08-27 more work on 3d-printed enclosure and PCB lid
    [base.FCStd]
2023-09-14 added gerber for lid and finalised gerber for both lid and PCB
    [base.FCStd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]
